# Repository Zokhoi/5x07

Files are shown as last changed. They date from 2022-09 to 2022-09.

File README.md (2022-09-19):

# Project 5x07

A low profile ortholinear split keyboard with per-key RGB.

This is a project that began as my first adventure into PCB and keyboard design.



## Parts required

**This table is for one PCB. You need double of this for both hands.**

| Part | Part Details | Quantity | Notes |
| --- | --- | --- | --- |
| [ATmega32u4-AU](https://item.taobao.com/item.htm?id=677430063008) | TQFP-44 | 1 | |
| [Korean Hroparts Elec TYPE-C-31-M-12](https://www.lcsc.com/product-detail/USB-Type-C_Korean-Hroparts-Elec-TYPE-C-31-M-12_C165948.html) | | 1 | |
| [Korean Hroparts ELEC PJ-3200B-4A TRRS Jack](https://www.lcsc.com/product-detail/Audio-Video-Connectors_Korean-Hroparts-Elec-PJ-3200B-4A_C136687.html) | | 1 | For split keyboard connection |
| [SK6812 Mini-E Reverse Mount LED](https://item.taobao.com/item.htm?id=669061805532) | | 35 | |
| [16MHz 3225 SMD Crystal](https://lcsc.com/product-detail/Crystals_Seiko-Epson-X1E000021061300_C255909.html) | | 1 | |
| [PRTR5V0U2X](https://lcsc.com/product-detail/Diodes-ESD_Nexperia-PRTR5V0U2X-215_C12333.html) | SOT143B | | For ESD protection |
| [SKQG push button switch](https://lcsc.com/product-detail/Tactile-Switches_ALPSALPINE-SKQGAFE010_C202424.html) | | 1 | For reset circuit |
| 0608/2012 SMD Resistor | [10kΩ](https://lcsc.com/product-detail/Chip-Resistor-Surface-Mount_Viking-Tech-AR05BTCW1002_C316200.html) | 3 | For MCU HWB and TRRS jack (i2c) |
| | [500Ω](https://lcsc.com/product-detail/Chip-Resistor-Surface-Mount_Viking-Tech-ARG05BTC5000_C2828711.html) | 1 | For keyboard LED |
| | [5.1kΩ](https://lcsc.com/product-detail/Chip-Resistor-Surface-Mount_Viking-Tech-AR05DTCW5101_C319564.html) | 2 | For USB-C CC |
| | [22Ω](https://lcsc.com/product-detail/Chip-Resistor-Surface-Mount_Viking-Tech-ARG05BTC0220_C309084.html) | 2 | For USB-C data |
| | [330Ω](https://lcsc.com/product-detail/Chip-Resistor-Surface-Mount_Viking-Tech-ARG05BTC3300_C2984456.html) | 1 | For reset circuit |
| 1206/3212 SMD Fuse | [500mA](https://lcsc.com/product-detail/PTC-Resettable-Fuses_TECHFUSE-nSMD025-24V_C70069.html) | 1 | |
| Diodes | [1N4148](https://lcsc.com/product-detail/Switching-Diode_MCC-Micro-Commercial-Components-1N4148W-TP_C77978.html) or SMD | 35 | For keyboard matrix |
| | [Schottky](https://lcsc.com/product-detail/Schottky-Barrier-Diodes-SBD_Shikues-B5817WL_C122853.html) | 1 | For USB-C power |
| 0805 SMD Capacitors | [22 pF](https://lcsc.com/product-detail/Multilayer-Ceramic-Capacitors-MLCC-SMD-SMT_Samsung-Electro-Mechanics-CL21C220JCANNNC_C165459.html) | 2 | For crystal |
| | [1 uF](https://lcsc.com/product-detail/Multilayer-Ceramic-Capacitors-MLCC-SMD-SMT_Samsung-Electro-Mechanics_CL21B105KAFNNNE_Samsung-Electro-Mechanics-CL21B105KAFNNNE_C11635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) | 1 | For MCU UCAP |
| | [10 uF](https://lcsc.com/product-detail/Multilayer-Ceramic-Capacitors-MLCC-SMD-SMT_SAMSUNG_CL21B106KOQNNNE_10uF-106-10-16V_C95841.html) | 1 | For decoupling |
| | [0.1 uF](https://lcsc.com/product-detail/Multilayer-Ceramic-Capacitors-MLCC-SMD-SMT_SAMSUNG_CL21B104JBCNNNC_100nF-104-5-50V_C62912.html) | 4 | For decoupling |
| M2 screws | >=3mm | 8 | For bottom plate, length for reference only |
| M2 standoff | 3mm | 4 | For bottom plate, length for reference only |

## Board details

Fabrication gerber files are in `./PCB/gerber` directory.

103.188 mm H x 168.275 mm W <br />
2 layers <br />
Unleaded HASL or ENIG <br />
1.6mm thick <br />
white on black

## Assembly instructions

The images below are PCBs for v3.





The board is designed to be reversible. You can flip the PCB to the other side to serve as the other half.

The parts that are mountable on both sides of the PCB are the type C port, the TRRS jack, the reset button and the key matrix (switch, LED, diode).

The side for mounting type C port and TRRS jack is up to your will. The reset button should always face up for ease of access. The LEDs for keyboard are reverse mounted. Key diodes should be on the underside.

As one side would have its electrionic components mostly facing down, you should lift the split halves up to avoid shorting. If you have leftover boards from ordering in batch amounts, it is possible to use them as bottom plates using M2 screws and standoffs. 

For information, the shortest M2 standoffs I can find are 3mm in length, the type C port is 3.2mm high, and the TRRS jack is 5mm high (the outer plastic ring might be 5.6mm high). If you decide to put the type C port and TRRS jack on the top side, you can have the standoff as short as just higher than the electronic components on the board.

## Build instructions

By default the keyboard is set to use EEPROM handedness check, this means that
for the first time for both halves the following commands need to be used:

```bash
make 5x07:default:dfu-split-left
make 5x07:default:dfu-split-right
```

afterwards the end part can be dropped when flashing again.

For v3 and below there is no VBUS detection, so USB activity detection must be used for split master detection if you do not want to hardcode the master half. <br />
V3.1 onwards has VBUS detection and you can use it normally.

## CAUTIONS

I couldn't for the life of me figure out how to stably enable the per key RGB, so use at your own risk.

Some problems that I encountered were:

* RHS board (using EEPROM flags) could have RGB lights on in QMK, but then it disconnects if the mode switches from the static gradient to static solid color.
* RHS board can change modes between different static gradients if its hue/saturation/value are turned down first.
* LHS board disconnects from computer immediately after connection when RGB is enabled. If the USB is connected to RHS board and LHS is connected to RHS via i2c, it would drag both halves down with the disconnection. After disconnection, the RGB lights start to flicker.
* RHS board would also display random disconnection behavior if the hsv are changed too fast.

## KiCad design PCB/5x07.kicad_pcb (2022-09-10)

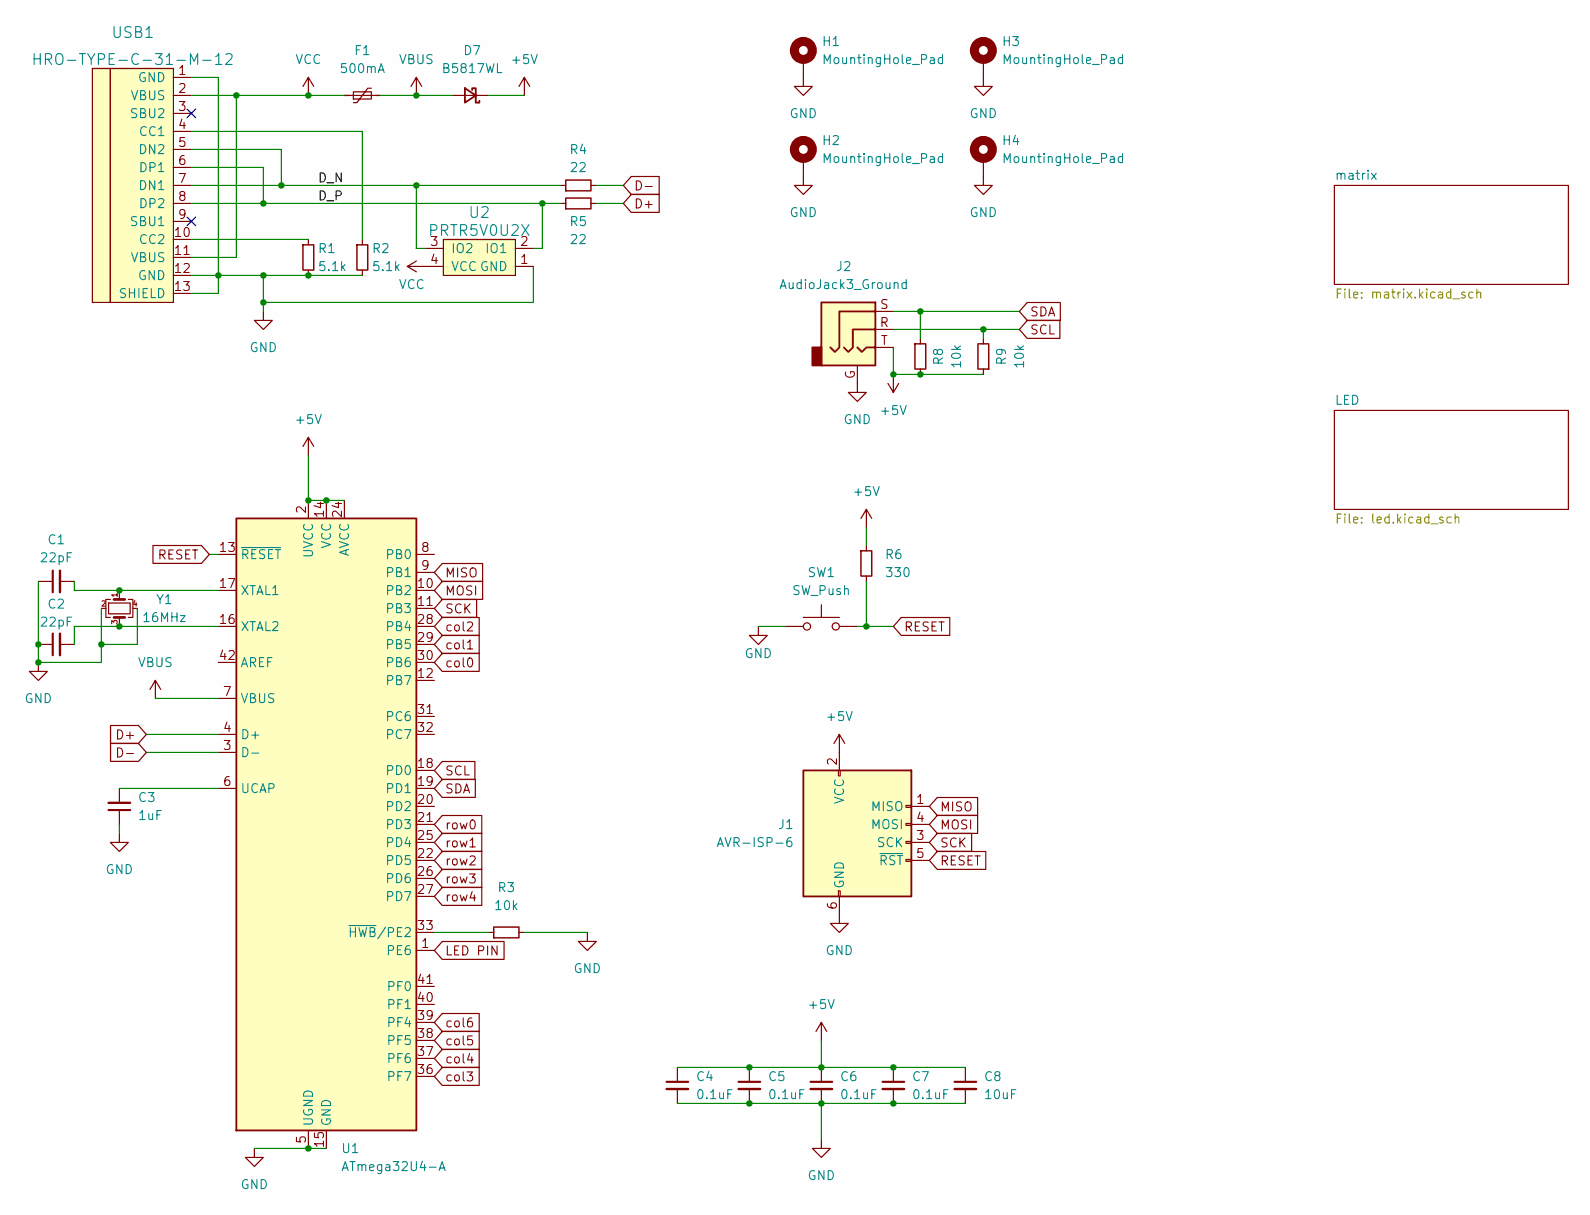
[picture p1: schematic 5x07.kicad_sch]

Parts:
C1, C2: 22pF; C_0805_2012Metric_Pad1.18x1.45mm_HandSolder
C3: 1uF; C_0805_2012Metric_Pad1.18x1.45mm_HandSolder
C4, C5, C6, C7: 0.1uF; C_0805_2012Metric_Pad1.18x1.45mm_HandSolder
C8: 10uF; C_0805_2012Metric_Pad1.18x1.45mm_HandSolder
D7: B5817WL; D_SOD-123F
F1: 500mA; Fuse_1206_3216Metric_Pad1.42x1.75mm_HandSolder
H1, H2, H3, H4: MountingHole_Pad; Generic-Mounthole
J1: AVR-ISP-6; Reset_Pretty
J2: AudioJack3_Ground; PJ-3200B-4A-Reversible-Mini
R1, R2: 5.1k; R_0805_2012Metric_Pad1.20x1.40mm_HandSolder
R3, R8, R9: 10k; R_0805_2012Metric_Pad1.20x1.40mm_HandSolder
R4, R5: 22; R_0805_2012Metric_Pad1.20x1.40mm_HandSolder
R6: 330; R_0805_2012Metric_Pad1.20x1.40mm_HandSolder
SW1: SW_Push; SW_SPST_SKQG_WithStem_Reversible
U1: ATmega32U4-A; TQFP-44_10x10mm_P0.8mm
U2: PRTR5V0U2X; SOT143B
USB1: HRO-TYPE-C-31-M-12; HRO-TYPE-C-31-M-12-HandSoldering-Reversible
Y1: 16MHz; Crystal_SMD_3225-4Pin_3.2x2.5mm_HandSoldering

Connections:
+5V: C4.1, C5.1, C6.1, C7.1, C8.1, D7.1 (K), J1.2 (VCC), J2.T, R6.1, R8.2, R9.1, U1.2 (UVCC), U1.14 (VCC), U1.24 (AVCC), U1.34 (VCC), U1.44 (AVCC); also elsewhere on the board
/D_N: R4.1, U2.3 (IO2), USB1.5 (DN2), USB1.7 (DN1)
/D_P: R5.1, U2.2 (IO1), USB1.6 (DP1), USB1.8 (DP2)
D+: R5.2, U1.4 (D+)
D-: R4.2, U1.3 (D-)
GND: C1.1, C2.1, C3.1, C4.2, C5.2, C6.2, C7.2, C8.2, H1.1, H2.1, H3.1, H4.1, J1.6 (GND), J2.G, R1.2, R2.2, R3.2, SW1.1, U1.5 (UGND), U1.15 (GND), U1.23 (GND), U1.35 (GND), U1.43 (GND), U2.1 (GND), USB1.1 (GND), USB1.12 (GND), USB1.13 (SHIELD), Y1.2, Y1.4; also elsewhere on the board
LED PIN: U1.1 (PE6); also elsewhere on the board
MISO: J1.1 (MISO), U1.9 (PB1)
MOSI: J1.4 (MOSI), U1.10 (PB2)
unnamed: C1.2, U1.17 (XTAL1), Y1.1
unnamed: C2.2, U1.16 (XTAL2), Y1.3
unnamed: C3.2, U1.6 (UCAP)
unnamed: R1.1, USB1.10 (CC2)
unnamed: R2.1, USB1.4 (CC1)
unnamed: R3.1, U1.33 (~HWB/PE2)
RESET: J1.5 (~RST), R6.2, SW1.2, U1.13 (~RESET)
SCK: J1.3 (SCK), U1.11 (PB3)
SCL: J2.R, R9.2, U1.18 (PD0)
SDA: J2.S, R8.1, U1.19 (PD1)
VCC: F1.1, U2.4 (VCC), USB1.2 (VBUS), USB1.11 (VBUS)
col0: U1.30 (PB6); also elsewhere on the board
col1: U1.29 (PB5); also elsewhere on the board
col2: U1.28 (PB4); also elsewhere on the board
col3: U1.36 (PF7); also elsewhere on the board
col4: U1.37 (PF6); also elsewhere on the board
col5: U1.38 (PF5); also elsewhere on the board
col6: U1.39 (PF4); also elsewhere on the board
row0: U1.21 (PD3); also elsewhere on the board
row1: U1.25 (PD4); also elsewhere on the board
row2: U1.22 (PD5); also elsewhere on the board
row3: U1.26 (PD6); also elsewhere on the board
row4: U1.27 (PD7); also elsewhere on the board

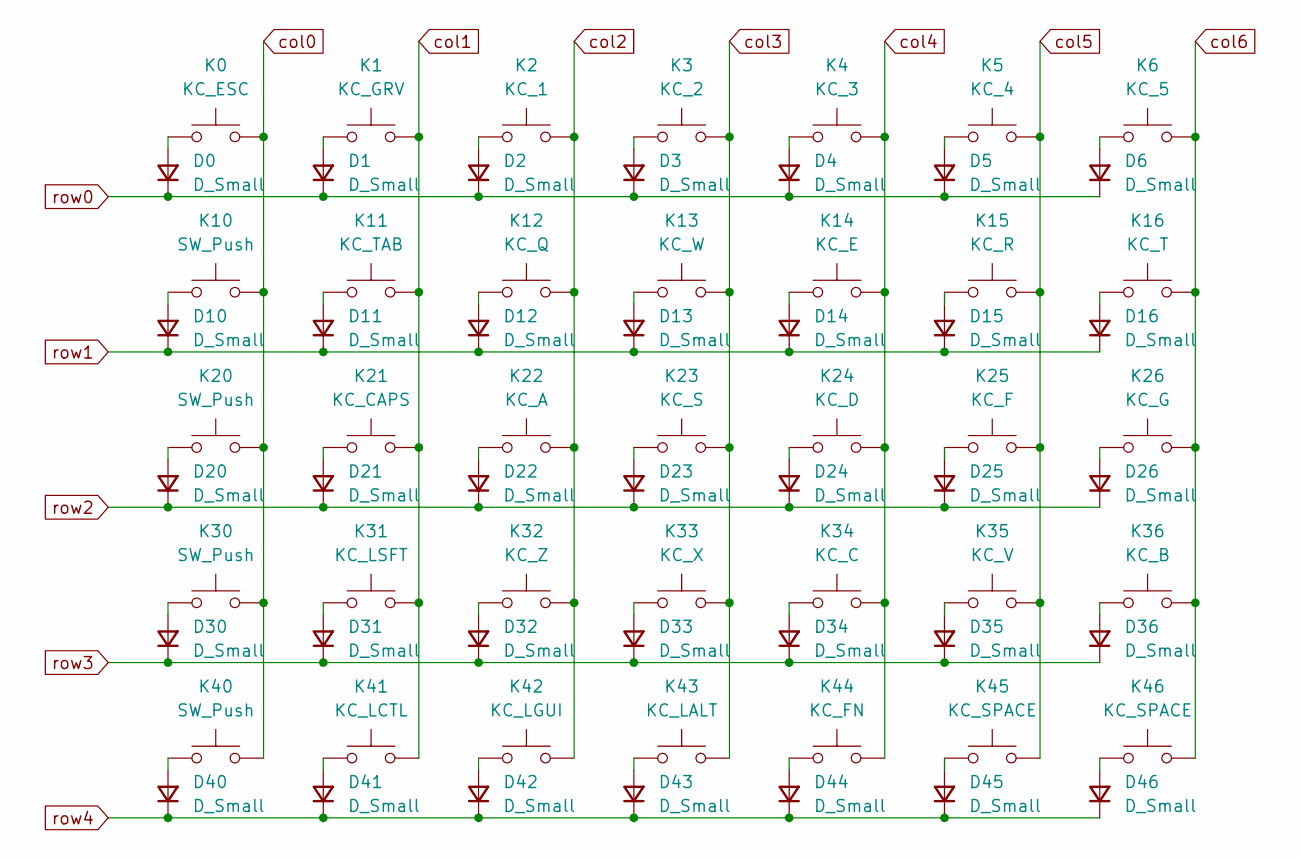
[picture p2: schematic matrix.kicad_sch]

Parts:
D0, D1, D2, D3, D4, D5, D6, D10, D11, D12, D13, D14, D15, D16, D20, D21, D22, D23, D24, D25, D26, D30, D31, D32, D33, D34, D35, D36, D40, D41, D42, D43, D44, D45, D46: D_Small; D_SOD-123-Reversible
K0: KC_ESC; SW_choc_1u_reversible
K1: KC_GRV; SW_choc_1u_reversible
K2: KC_1; SW_choc_1u_reversible
K3: KC_2; SW_choc_1u_reversible
K4: KC_3; SW_choc_1u_reversible
K5: KC_4; SW_choc_1u_reversible
K6: KC_5; SW_choc_1u_reversible
K10, K20, K30, K40: SW_Push; SW_choc_1u_reversible
K11: KC_TAB; SW_choc_1u_reversible
K12: KC_Q; SW_choc_1u_reversible
K13: KC_W; SW_choc_1u_reversible
K14: KC_E; SW_choc_1u_reversible
K15: KC_R; SW_choc_1u_reversible
K16: KC_T; SW_choc_1u_reversible
K21: KC_CAPS; SW_choc_1u_reversible
K22: KC_A; SW_choc_1u_reversible
K23: KC_S; SW_choc_1u_reversible
K24: KC_D; SW_choc_1u_reversible
K25: KC_F; SW_choc_1u_reversible
K26: KC_G; SW_choc_1u_reversible
K31: KC_LSFT; SW_choc_1u_reversible
K32: KC_Z; SW_choc_1u_reversible
K33: KC_X; SW_choc_1u_reversible
K34: KC_C; SW_choc_1u_reversible
K35: KC_V; SW_choc_1u_reversible
K36: KC_B; SW_choc_1u_reversible
K41: KC_LCTL; SW_choc_1u_reversible
K42: KC_LGUI; SW_choc_1u_reversible
K43: KC_LALT; SW_choc_1u_reversible
K44: KC_FN; SW_choc_1u_reversible
K45, K46: KC_SPACE; SW_choc_1u_reversible

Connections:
unnamed: D0.2 (A), K0.1
unnamed: D1.2 (A), K1.1
unnamed: D2.2 (A), K2.1
unnamed: D3.2 (A), K3.1
unnamed: D4.2 (A), K4.1
unnamed: D5.2 (A), K5.1
unnamed: D6.2 (A), K6.1
unnamed: D10.2 (A), K10.1
unnamed: D11.2 (A), K11.1
unnamed: D12.2 (A), K12.1
unnamed: D13.2 (A), K13.1
unnamed: D14.2 (A), K14.1
unnamed: D15.2 (A), K15.1
unnamed: D16.2 (A), K16.1
unnamed: D20.2 (A), K20.1
unnamed: D21.2 (A), K21.1
unnamed: D22.2 (A), K22.1
unnamed: D23.2 (A), K23.1
unnamed: D24.2 (A), K24.1
unnamed: D25.2 (A), K25.1
unnamed: D26.2 (A), K26.1
unnamed: D30.2 (A), K30.1
unnamed: D31.2 (A), K31.1
unnamed: D32.2 (A), K32.1
unnamed: D33.2 (A), K33.1
unnamed: D34.2 (A), K34.1
unnamed: D35.2 (A), K35.1
unnamed: D36.2 (A), K36.1
unnamed: D40.2 (A), K40.1
unnamed: D41.2 (A), K41.1
unnamed: D42.2 (A), K42.1
unnamed: D43.2 (A), K43.1
unnamed: D44.2 (A), K44.1
unnamed: D45.2 (A), K45.1
unnamed: D46.2 (A), K46.1
col0: K0.2, K10.2, K20.2, K30.2, K40.2; also elsewhere on the board
col1: K1.2, K11.2, K21.2, K31.2, K41.2; also elsewhere on the board
col2: K2.2, K12.2, K22.2, K32.2, K42.2; also elsewhere on the board
col3: K3.2, K13.2, K23.2, K33.2, K43.2; also elsewhere on the board
col4: K4.2, K14.2, K24.2, K34.2, K44.2; also elsewhere on the board
col5: K5.2, K15.2, K25.2, K35.2, K45.2; also elsewhere on the board
col6: K6.2, K16.2, K26.2, K36.2, K46.2; also elsewhere on the board
row0: D0.1 (K), D1.1 (K), D2.1 (K), D3.1 (K), D4.1 (K), D5.1 (K), D6.1 (K); also elsewhere on the board
row1: D10.1 (K), D11.1 (K), D12.1 (K), D13.1 (K), D14.1 (K), D15.1 (K), D16.1 (K); also elsewhere on the board
row2: D20.1 (K), D21.1 (K), D22.1 (K), D23.1 (K), D24.1 (K), D25.1 (K), D26.1 (K); also elsewhere on the board
row3: D30.1 (K), D31.1 (K), D32.1 (K), D33.1 (K), D34.1 (K), D35.1 (K), D36.1 (K); also elsewhere on the board
row4: D40.1 (K), D41.1 (K), D42.1 (K), D43.1 (K), D44.1 (K), D45.1 (K), D46.1 (K); also elsewhere on the board

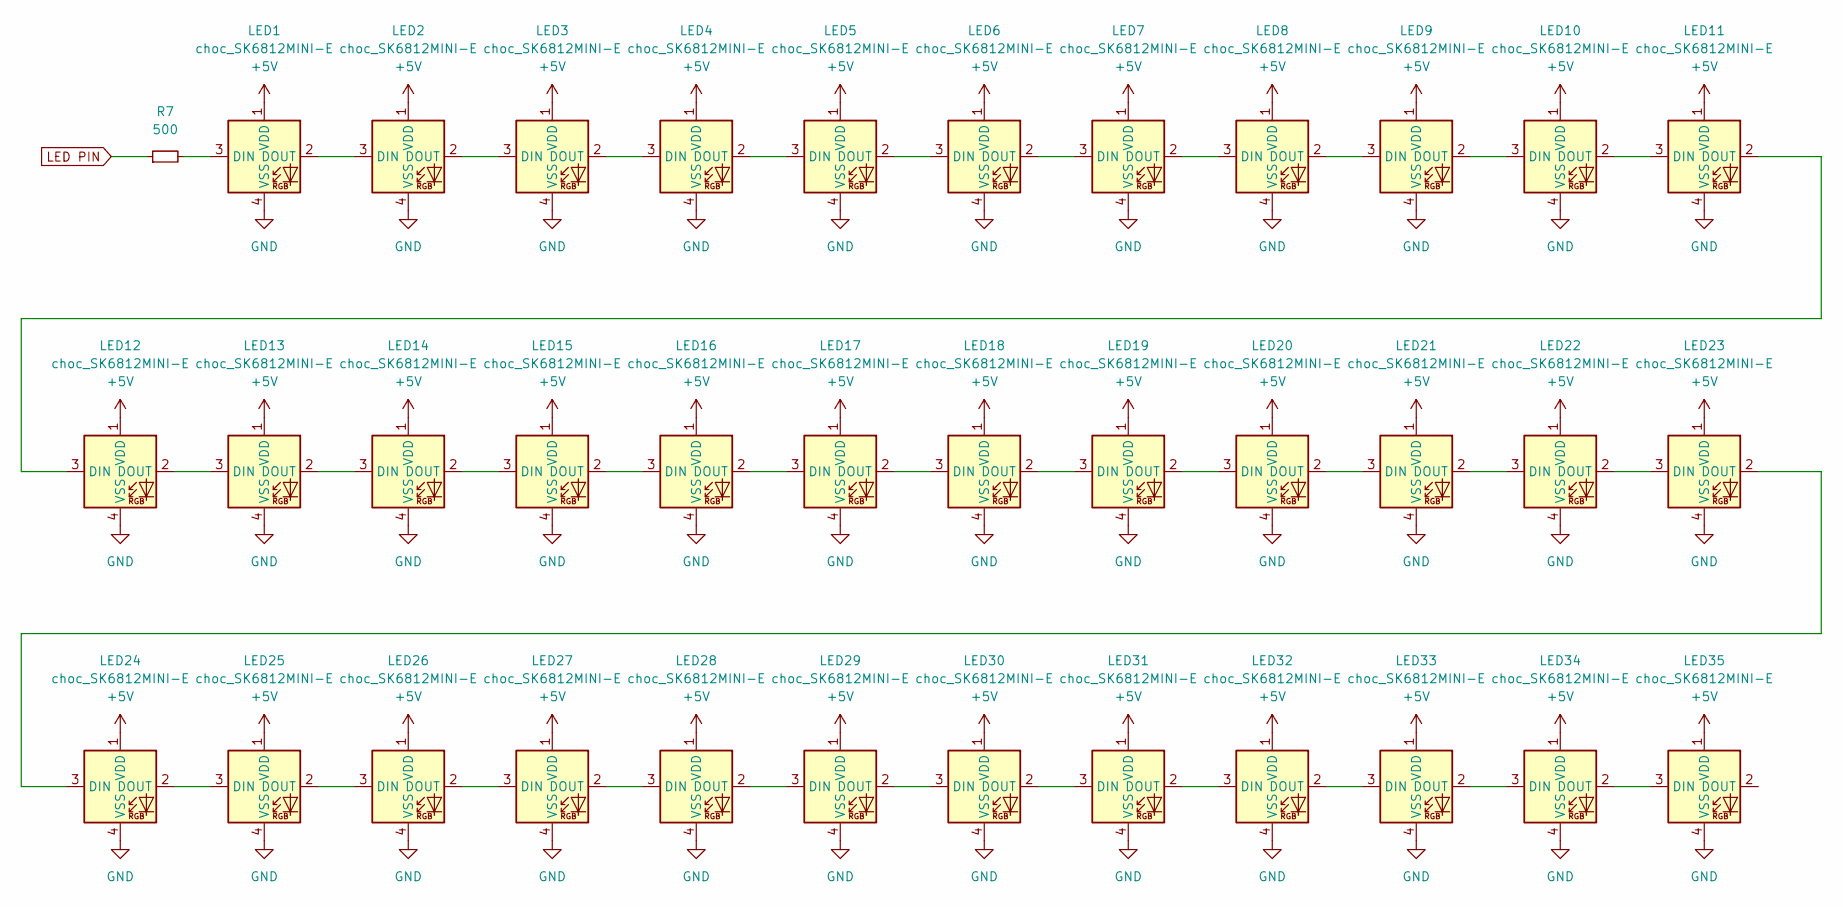
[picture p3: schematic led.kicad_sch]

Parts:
LED1, LED2, LED3, LED4, LED5, LED6, LED7, LED8, LED9, LED10, LED11, LED12, LED13, LED14, LED15, LED16, LED17, LED18, LED19, LED20, LED21, LED22, LED23, LED24, LED25, LED26, LED27, LED28, LED29, LED30, LED31, LED32, LED33, LED34, LED35: choc_SK6812MINI-E; LED_choc_6028R_Reversible_same_side
R7: 500; R_0805_2012Metric_Pad1.20x1.40mm_HandSolder

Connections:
+5V: LED1.1 (VDD), LED2.1 (VDD), LED3.1 (VDD), LED4.1 (VDD), LED5.1 (VDD), LED6.1 (VDD), LED7.1 (VDD), LED8.1 (VDD), LED9.1 (VDD), LED10.1 (VDD), LED11.1 (VDD), LED12.1 (VDD), LED13.1 (VDD), LED14.1 (VDD), LED15.1 (VDD), LED16.1 (VDD), LED17.1 (VDD), LED18.1 (VDD), LED19.1 (VDD), LED20.1 (VDD), LED21.1 (VDD), LED22.1 (VDD), LED23.1 (VDD), LED24.1 (VDD), LED25.1 (VDD), LED26.1 (VDD), LED27.1 (VDD), LED28.1 (VDD), LED29.1 (VDD), LED30.1 (VDD), LED31.1 (VDD), LED32.1 (VDD), LED33.1 (VDD), LED34.1 (VDD), LED35.1 (VDD); also elsewhere on the board
GND: LED1.4 (VSS), LED2.4 (VSS), LED3.4 (VSS), LED4.4 (VSS), LED5.4 (VSS), LED6.4 (VSS), LED7.4 (VSS), LED8.4 (VSS), LED9.4 (VSS), LED10.4 (VSS), LED11.4 (VSS), LED12.4 (VSS), LED13.4 (VSS), LED14.4 (VSS), LED15.4 (VSS), LED16.4 (VSS), LED17.4 (VSS), LED18.4 (VSS), LED19.4 (VSS), LED20.4 (VSS), LED21.4 (VSS), LED22.4 (VSS), LED23.4 (VSS), LED24.4 (VSS), LED25.4 (VSS), LED26.4 (VSS), LED27.4 (VSS), LED28.4 (VSS), LED29.4 (VSS), LED30.4 (VSS), LED31.4 (VSS), LED32.4 (VSS), LED33.4 (VSS), LED34.4 (VSS), LED35.4 (VSS); also elsewhere on the board
LED PIN: R7.1; also elsewhere on the board
unnamed: LED1.2 (DOUT), LED2.3 (DIN)
unnamed: LED1.3 (DIN), R7.2
unnamed: LED2.2 (DOUT), LED3.3 (DIN)
unnamed: LED3.2 (DOUT), LED4.3 (DIN)
unnamed: LED4.2 (DOUT), LED5.3 (DIN)
unnamed: LED5.2 (DOUT), LED6.3 (DIN)
unnamed: LED6.2 (DOUT), LED7.3 (DIN)
unnamed: LED7.2 (DOUT), LED8.3 (DIN)
unnamed: LED8.2 (DOUT), LED9.3 (DIN)
unnamed: LED10.2 (DOUT), LED11.3 (DIN)
unnamed: LED9.2 (DOUT), LED10.3 (DIN)
unnamed: LED11.2 (DOUT), LED12.3 (DIN)
unnamed: LED12.2 (DOUT), LED13.3 (DIN)
unnamed: LED13.2 (DOUT), LED14.3 (DIN)
unnamed: LED14.2 (DOUT), LED15.3 (DIN)
unnamed: LED15.2 (DOUT), LED16.3 (DIN)
unnamed: LED16.2 (DOUT), LED17.3 (DIN)
unnamed: LED17.2 (DOUT), LED18.3 (DIN)
unnamed: LED18.2 (DOUT), LED19.3 (DIN)
unnamed: LED19.2 (DOUT), LED20.3 (DIN)
unnamed: LED20.2 (DOUT), LED21.3 (DIN)
unnamed: LED21.2 (DOUT), LED22.3 (DIN)
unnamed: LED22.2 (DOUT), LED23.3 (DIN)
unnamed: LED23.2 (DOUT), LED24.3 (DIN)
unnamed: LED24.2 (DOUT), LED25.3 (DIN)
unnamed: LED25.2 (DOUT), LED26.3 (DIN)
unnamed: LED26.2 (DOUT), LED27.3 (DIN)
unnamed: LED27.2 (DOUT), LED28.3 (DIN)
unnamed: LED28.2 (DOUT), LED29.3 (DIN)
unnamed: LED29.2 (DOUT), LED30.3 (DIN)
unnamed: LED30.2 (DOUT), LED31.3 (DIN)
unnamed: LED31.2 (DOUT), LED32.3 (DIN)
unnamed: LED32.2 (DOUT), LED33.3 (DIN)
unnamed: LED33.2 (DOUT), LED34.3 (DIN)
unnamed: LED34.2 (DOUT), LED35.3 (DIN)

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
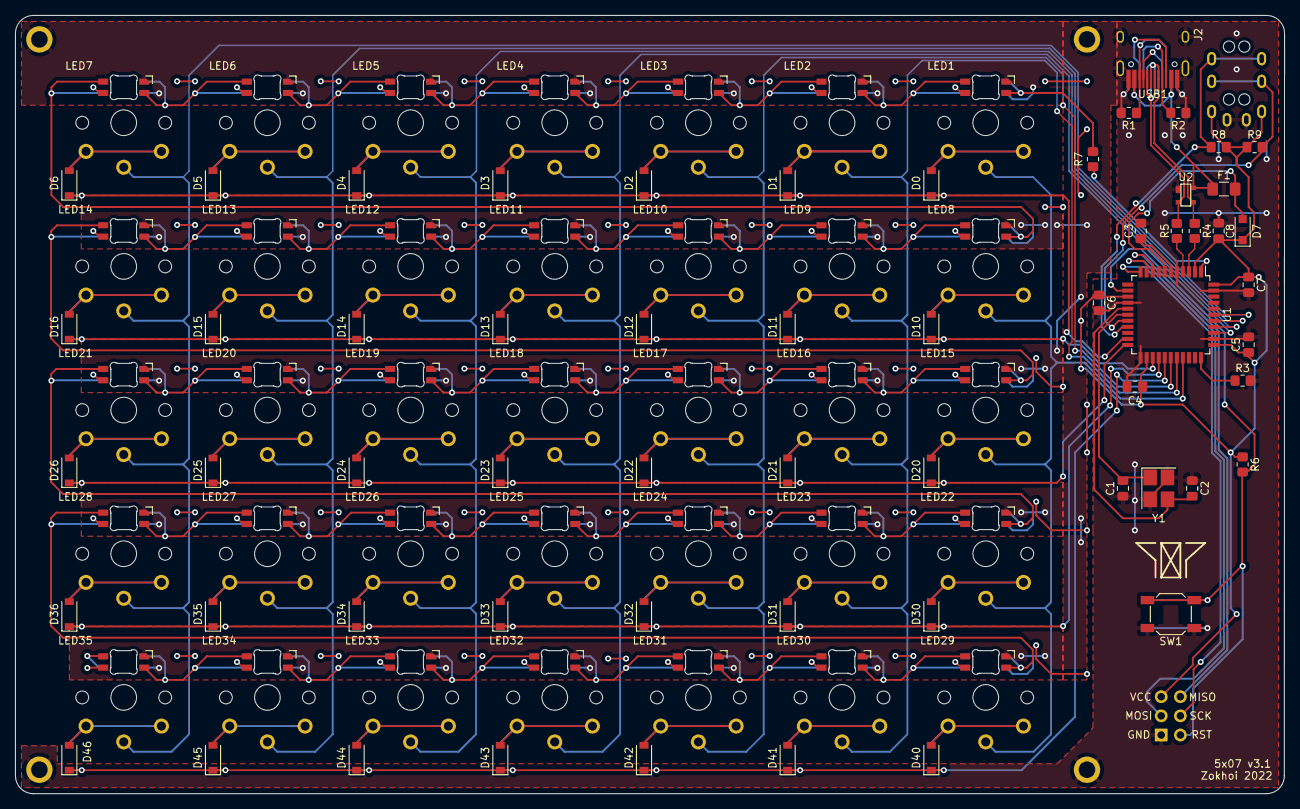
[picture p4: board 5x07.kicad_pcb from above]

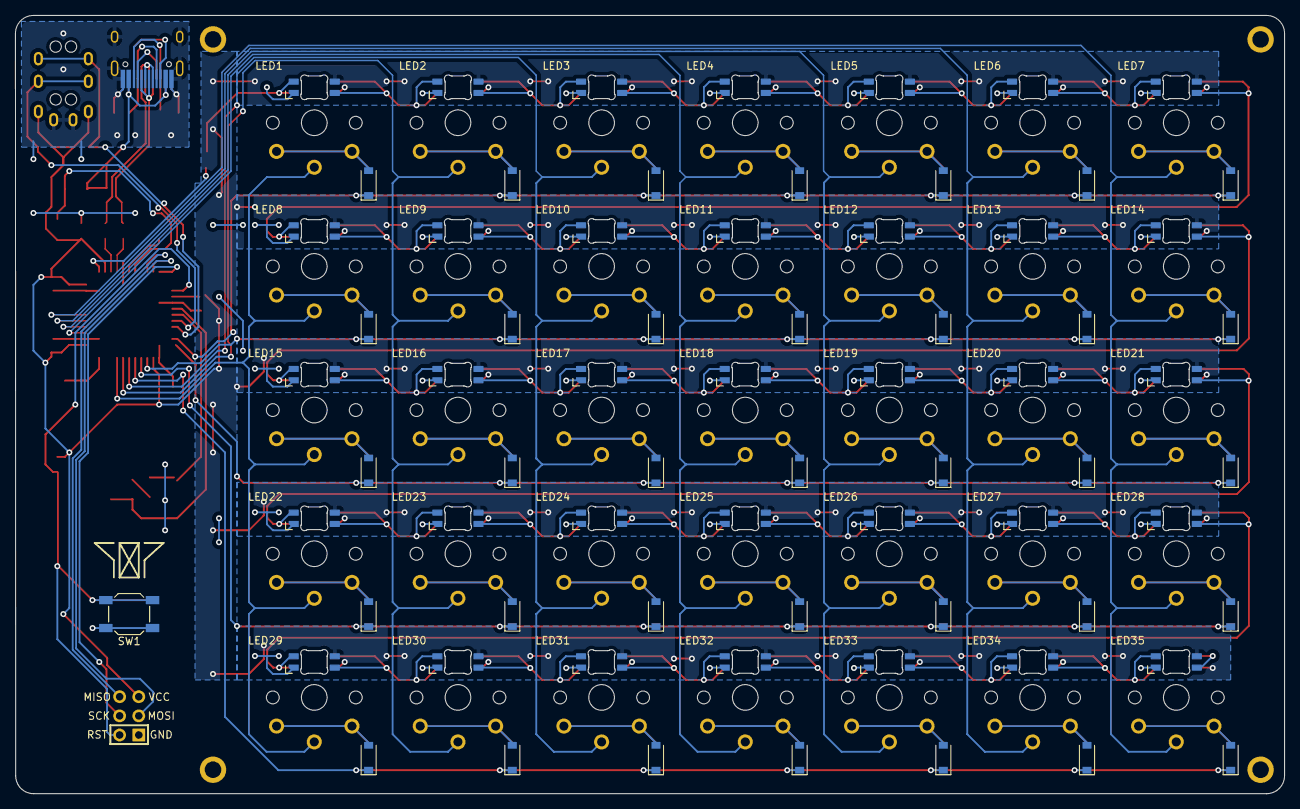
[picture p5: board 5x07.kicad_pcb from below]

Board: 2 copper layers, 168.3 x 103.2 mm, 135 parts (37 on the bottom side), 103 nets.

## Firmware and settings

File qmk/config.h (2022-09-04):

/* Copyright 2022 Zokhoi
 *
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
 * You should have received a copy of the GNU General Public License
 * along with this program.  If not, see <http://www.gnu.org/licenses/>.
 */

#pragma once

#include "config_common.h"

/* key matrix size */
// Rows are doubled-up
#define MATRIX_ROWS 10
#define MATRIX_COLS 7

/*
 * Keyboard Matrix Assignments
 *
 * Change this to how you wired your keyboard
 * COLS: AVR pins used for columns, left to right
 * ROWS: AVR pins used for rows, top to bottom
 * DIODE_DIRECTION: COL2ROW = COL = Anode (+), ROW = Cathode (-, marked on diode)
 *                  ROW2COL = ROW = Anode (+), COL = Cathode (-, marked on diode)
 *
 */
#define MATRIX_ROW_PINS { D3, D4, D5, D6, D7 }
#define MATRIX_COL_PINS { B6, B5, B4, F7, F6, F5, F4 }

/* COL2ROW, ROW2COL */
#define DIODE_DIRECTION COL2ROW

/* Split Keyboard specific options */
#define USE_I2C
/* Storing handedness in EEPROM */
#define EE_HANDS
/* Detect master half by USB activity */
#define SPLIT_USB_DETECT
#define SPLIT_LAYER_STATE_ENABLE
#define SPLIT_MODS_ENABLE
#define SPLIT_TRANSPORT_MIRROR
#define SPLIT_MAX_CONNECTION_ERRORS 5

//#define BACKLIGHT_PIN E6
//#define BACKLIGHT_LEVELS 3
//#define BACKLIGHT_BREATHING
#ifdef RGBLIGHT_ENABLE
#    define RGB_DI_PIN E6
#    define RGBLED_NUM 70
#    define RGBLED_SPLIT { 35, 35 }

#    define RGBLIGHT_HUE_STEP 8
#    define RGBLIGHT_SAT_STEP 8
#    define RGBLIGHT_VAL_STEP 8
// #    define RGBLIGHT_DEFAULT_HUE 64
// #    define RGBLIGHT_DEFAULT_SAT 240
// #    define RGBLIGHT_DEFAULT_VAL RGBLIGHT_LIMIT_VAL
// #    define RGBLIGHT_ANIMATIONS
#    define RGBLIGHT_EFFECT_STATIC_GRADIENT
#    define RGBLIGHT_DEFAULT_MODE RGBLIGHT_MODE_STATIC_GRADIENT+5
#endif

#ifdef RGB_MATRIX_ENABLE
#    define RGB_DI_PIN E6
#    define RGBLED_NUM 70
#    define RGBLED_SPLIT { 35, 35 }
#    define DRIVER_LED_TOTAL RGBLED_NUM
#    define RGB_MATRIX_SPLIT RGBLED_SPLIT
#    define RGB_MATRIX_CENTER { 122, 32 }
#    define RGB_MATRIX_MAXIMUM_BRIGHTNESS 255
#    define RGB_MATRIX_STARTUP_VAL RGB_MATRIX_MAXIMUM_BRIGHTNESS
#    define RGB_MATRIX_KEYPRESSES
#    define RGB_MATRIX_SOLID_REACTIVE_SIMPLE
#    define RGBLIGHT_DEFAULT_HUE 64

// #    define RGBLIGHT_HUE_STEP 8
// #    define RGBLIGHT_SAT_STEP 8
// #    define RGBLIGHT_VAL_STEP 8
//#    define RGBLIGHT_LIMIT_VAL 255 /* The maximum brightness level */
//#    define RGBLIGHT_SLEEP  /* If defined, the RGB lighting will be switched off when the host goes to sleep */
/*== all animations enable ==*/
// #    define RGBLIGHT_ANIMATIONS
/*== or choose animations ==*/
//#    define RGBLIGHT_EFFECT_BREATHING
//#    define RGBLIGHT_EFFECT_RAINBOW_MOOD
//#    define RGBLIGHT_EFFECT_RAINBOW_SWIRL
//#    define RGBLIGHT_EFFECT_SNAKE
//#    define RGBLIGHT_EFFECT_KNIGHT
//#    define RGBLIGHT_EFFECT_CHRISTMAS
//#    define RGBLIGHT_EFFECT_STATIC_GRADIENT
//#    define RGBLIGHT_EFFECT_RGB_TEST
//#    define RGBLIGHT_EFFECT_ALTERNATING
/*== customize breathing effect ==*/
/*==== (DEFAULT) use fixed table instead of exp() and sin() ====*/
//#    define RGBLIGHT_BREATHE_TABLE_SIZE 256      // 256(default) or 128 or 64
/*==== use exp() and sin() ====*/
//#    define RGBLIGHT_EFFECT_BREATHE_CENTER 1.85  // 1 to 2.7
//#    define RGBLIGHT_EFFECT_BREATHE_MAX    255   // 0 to 255

#endif

/* Debounce reduces chatter (unintended double-presses) - set 0 if debouncing is not needed */
#define DEBOUNCE 2

/* define if matrix has ghost (lacks anti-ghosting diodes) */
//#define MATRIX_HAS_GHOST

/* Mechanical locking support. Use KC_LCAP, KC_LNUM or KC_LSCR instead in keymap */
// #define LOCKING_SUPPORT_ENABLE
/* Locking resynchronize hack */
// #define LOCKING_RESYNC_ENABLE

/* If defined, GRAVE_ESC will always act as ESC when CTRL is held.
 * This is useful for the Windows task manager shortcut (ctrl+shift+esc).
 */
//#define GRAVE_ESC_CTRL_OVERRIDE

/*
 * Force NKRO
 *
 * Force NKRO (nKey Rollover) to be enabled by default, regardless of the saved
 * state in the bootmagic EEPROM settings. (Note that NKRO must be enabled in the
 * makefile for this to work.)
 *
 * If forced on, NKRO can be disabled via magic key (default = LShift+RShift+N)
 * until the next keyboard reset.
 *
 * NKRO may prevent your keystrokes from being detected in the BIOS, but it is
 * fully operational during normal computer usage.
 *
 * For a less heavy-handed approach, enable NKRO via magic key (LShift+RShift+N)
 * or via bootmagic (hold SPACE+N while plugging in the keyboard). Once set by
 * bootmagic, NKRO mode will always be enabled until it is toggled again during a
 * power-up.
 *
 */
//#define FORCE_NKRO

/*
 * Feature disable options
 *  These options are also useful to firmware size reduction.
 */

/* disable debug print */
//#define NO_DEBUG

/* disable print */
//#define NO_PRINT

/* disable action features */
//#define NO_ACTION_LAYER
//#define NO_ACTION_TAPPING
//#define NO_ACTION_ONESHOT

/* Bootmagic Lite key configuration */
//#define BOOTMAGIC_LITE_ROW 0
//#define BOOTMAGIC_LITE_COLUMN 0

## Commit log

2022-08-05 init: v1
    [5x07-B_Cu.gbl, 5x07-B_Mask.gbs, 5x07-B_Paste.gbp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]
2022-08-06 v2: reversiblility for LHS and RHS
    [5x07.kicad_pcb, 5x07.kicad_sch, led.kicad_sch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]
2022-08-06 v3: TRRS for split sides
    [5x07-B_Cu.gbl, 5x07-B_Mask.gbs, 5x07-B_Paste.gbp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]
2022-08-11 minified TRRS jack footprint and other bugfixes
    [5x07-B_Cu.gbl, 5x07-B_Mask.gbs, 5x07-B_Paste.gbp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]
2022-09-04 added build pics and instructions
    [5x07-B_Cu.gbl, 5x07-B_Mask.gbs, 5x07-B_Paste.gbp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]
2022-09-10 added vbus detection compatibility
    [5x07-B_Cu.gbl, 5x07-B_Mask.gbs, 5x07-B_Paste.gbp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]

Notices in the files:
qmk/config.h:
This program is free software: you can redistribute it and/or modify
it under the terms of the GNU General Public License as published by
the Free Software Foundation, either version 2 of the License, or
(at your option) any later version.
